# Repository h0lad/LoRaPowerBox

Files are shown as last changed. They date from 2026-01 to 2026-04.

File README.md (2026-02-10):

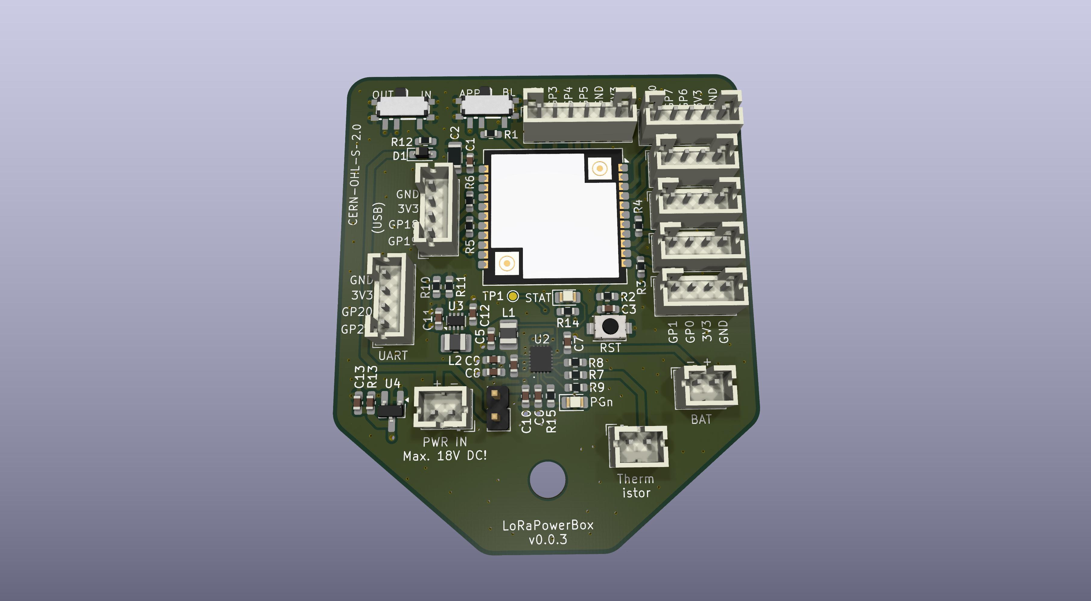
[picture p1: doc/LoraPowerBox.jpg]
LoRaPowerBox


## What is this thing?

This PCB integrates a Heltec HT-CT62 (ESP32-C3 + SX1262), a TI BQ25628E wide-range Li-ion charger and a TI TPS631000 buck-boost converter providing a stable 3.3V rail at up to 1.5A. The TI BQ25628E is capable of handling highly dynamic sources like solar cells and wind generators.

## Features

- 3.9-18V input range, with survival up to 26 V  
- Up to 3.2A input current (IBUS)  
- Up to 2A battery charge current (IBAT)  
- Up to 3.5A system output current (ISW), limited to 1.5A @ 3.3V by the TPS631000  
- Configurable hot/cold charging profile to restrict charging at extreme temperatures  
- Integrated ADC provides full voltage / current telemetry via I²C  
- Pseudo-MPPT (VINDPM + IINDPM) for improved energy harvesting from solar/wind/etc. sources
- Full protection circuitry, allowing operation even with unprotected LiPo cells  
- Reset IC (DI APX803L05) constantly monitors the battery voltage and switches off the 3.3V rail if it reaches a critical level - but keeps the charger always alive

You can see this project as a successor of the [SolarMeshtasticNode](https://github.com/h0lad/SolarMeshtasticNode) project which was a reliable work horse - but showed several limitations. 
Improvements:  

- No voltage dividers required - all measurements available via I²C from the charge controller
- No LED driver transistors needed
- Buck-architecture replaces inefficient LDO regulation
- Significantly improved access to interfaces

## Physical Outlines

The size of the PCB is 60mm x 51mm and is planned (= screw hole fits into housing) around following [Box (120x90x70)](https://de.aliexpress.com/item/1005005859929902.html). 

Do not use the transparent version: it will heat up.

**Simulation of the EdgeCut with a 1:1 print**

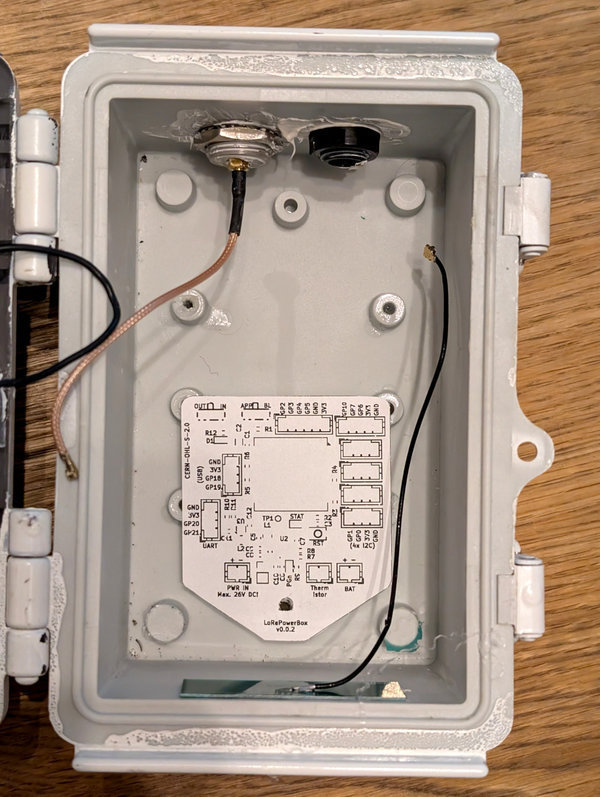
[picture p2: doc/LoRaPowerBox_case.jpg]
LoRaPowerBox


## Hardware Verification v0.2

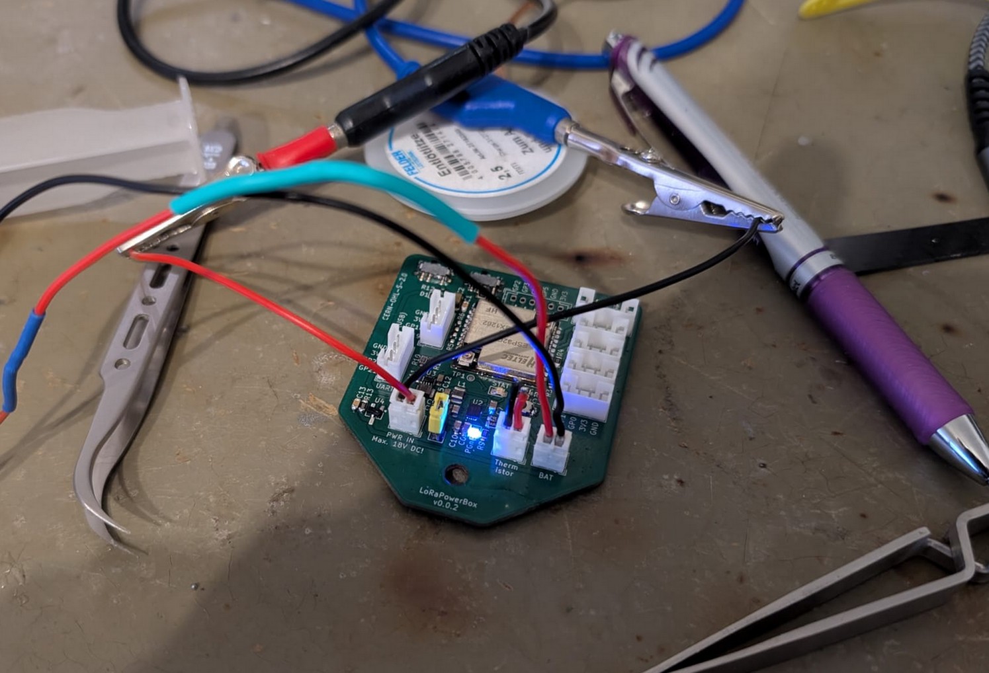
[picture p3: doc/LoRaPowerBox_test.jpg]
LoRaPowerBox


✅ Charging IC charges LiPo and blinks LED according to status

✅ Buck-Boost DCDC creates 3.3V

✅ Heating the thermistor forces throtteling of charging current

✅ Reset IC disables 3.3V using EN pin from DCDC if VBat falls below 3.2V

## FAQ

#### Why are you using a ESP32C3? 

I also do a lot of data gathering into TSDBs via Wifi. The Espressif has the most comfortable stack for doing this.

#### What pins does the LoRa module consume?

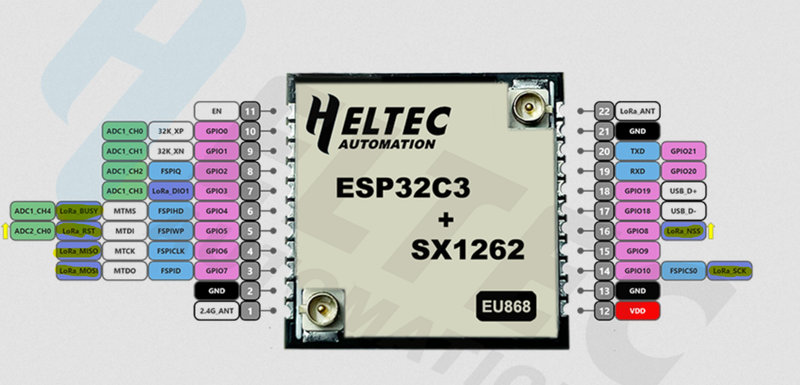
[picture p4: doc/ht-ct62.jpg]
Heltec HT-CT62


The Semtech SX1262 consumes a significant number of GPIOs.

Available pins If LoRa is being used: GPIO0, GPIO1, GPIO18, GPIO19, GPIO20, GPIO21

Note that GPIO8 and GPIO9 are strapping pins and are sampled during early boot.

If the SX1262 is not used, it can be disabled via its CS line (GPIO8) from application code.

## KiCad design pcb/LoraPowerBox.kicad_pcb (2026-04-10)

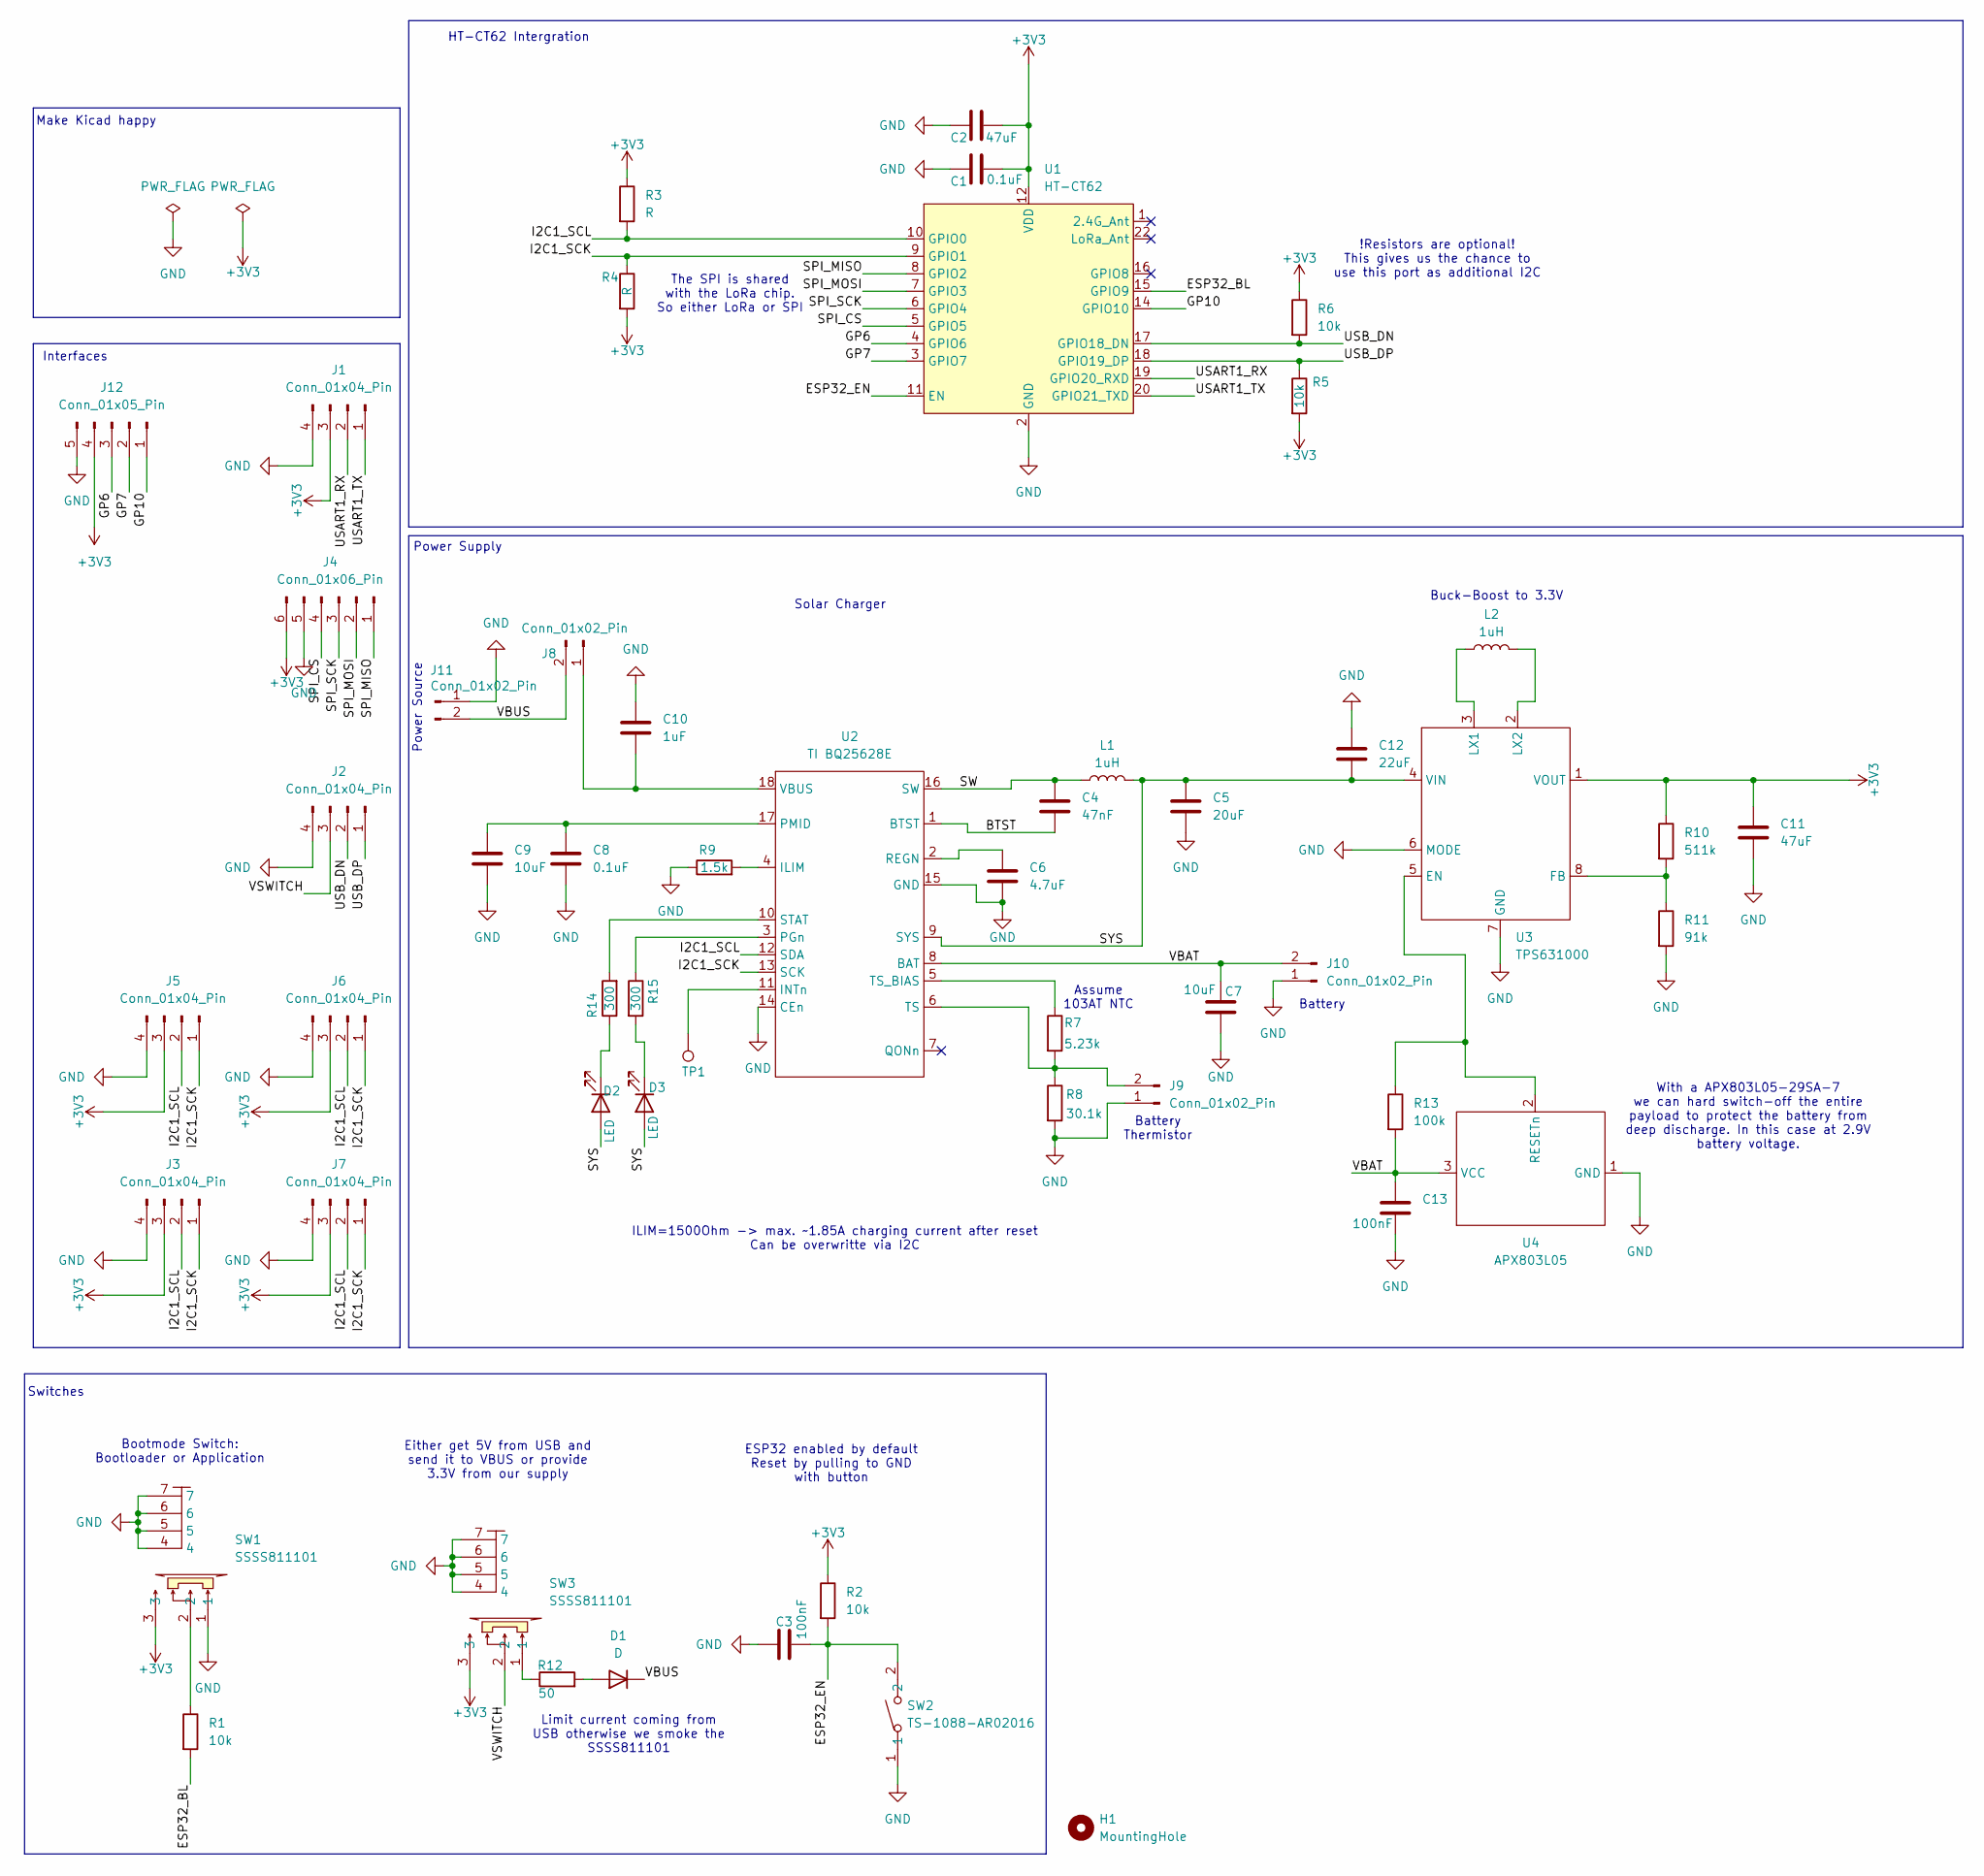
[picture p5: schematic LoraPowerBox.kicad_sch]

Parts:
C1, C8: 0.1uF; C_0603_1608Metric_Pad1.08x0.95mm_HandSolder
C2: 47uF; R_1206_3216Metric_Pad1.30x1.75mm_HandSolder
C3, C13: 100nF; C_0603_1608Metric_Pad1.08x0.95mm_HandSolder
C4: 47nF; C_0603_1608Metric_Pad1.08x0.95mm_HandSolder
C5: 20uF; C_0603_1608Metric_Pad1.08x0.95mm_HandSolder
C6: 4.7uF; C_0603_1608Metric_Pad1.08x0.95mm_HandSolder
C7, C9: 10uF; C_0603_1608Metric_Pad1.08x0.95mm_HandSolder
C10: 1uF; C_0603_1608Metric_Pad1.08x0.95mm_HandSolder
C11: 47uF; C_0603_1608Metric_Pad1.08x0.95mm_HandSolder
C12: 22uF; C_0603_1608Metric_Pad1.08x0.95mm_HandSolder
D1: D; D_SOD-323_HandSoldering
D2, D3: LED; LED_0805_2012Metric_Pad1.15x1.40mm_HandSolder
H1: MountingHole; MountingHole_4.3mm_M4_DIN965
J1, J2, J3, J5, J6, J7: Conn_01x04_Pin; JST_PH_B4B-PH-K_1x04_P2.00mm_Vertical
J4: Conn_01x06_Pin; JST_PH_B6B-PH-K_1x06_P2.00mm_Vertical
J8: Conn_01x02_Pin; PinHeader_1x02_P2.54mm_Vertical
J9, J10, J11: Conn_01x02_Pin; JST_PH_B2B-PH-K_1x02_P2.00mm_Vertical
J12: Conn_01x05_Pin; JST_PH_B5B-PH-K_1x05_P2.00mm_Vertical
L1, L2: 1uH; L_1008_2520Metric_Pad1.43x2.20mm_HandSolder
R1, R2, R5, R6: 10k; R_0603_1608Metric_Pad0.98x0.95mm_HandSolder
R3, R4: R; R_0603_1608Metric_Pad0.98x0.95mm_HandSolder
R7: 5.23k; R_0603_1608Metric_Pad0.98x0.95mm_HandSolder
R8: 30.1k; R_0603_1608Metric_Pad0.98x0.95mm_HandSolder
R9: 1.5k; R_0603_1608Metric_Pad0.98x0.95mm_HandSolder
R10: 511k; R_0603_1608Metric_Pad0.98x0.95mm_HandSolder
R11: 91k; R_0603_1608Metric_Pad0.98x0.95mm_HandSolder
R12: 50; R_0603_1608Metric_Pad0.98x0.95mm_HandSolder
R13: 100k; C_0603_1608Metric_Pad1.08x0.95mm_HandSolder
R14, R15: 300; R_0603_1608Metric_Pad0.98x0.95mm_HandSolder
SW1, SW3: SSSS811101; SW-SMD_SSSS811101; LCSC Part C109335
SW2: TS-1088-AR02016; SW-SMD_L3.9-W3.0-P4.45; LCSC Part C720477
TP1: TestPoint; TestPoint_Pad_D1.0mm
U1: HT-CT62; Heltec_HT-CT62
U2: TI BQ25628E; BQ25622ERYKR
U3: TPS631000; SOT-583-8
U4: APX803L05; SOT-23_Handsoldering

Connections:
+3V3: C1.2, C2.2, C11.1, J1.3, J3.3, J4.6, J5.3, J6.3, J7.3, J12.4, R2.1, R3.1, R4.2, R5.2, R6.1, R10.1, SW1.3, SW3.3, U1.12 (VDD), U3.1 (VOUT)
/BTST: C4.1, U2.1 (BTST)
/ESP32_BL: R1.2, U1.15 (GPIO9)
/ESP32_EN: C3.2, R2.2, SW2.2, U1.11 (EN)
/GP6: J12.3, U1.4 (GPIO6)
/GP7: J12.2, U1.3 (GPIO7)
/GP10: J12.1, U1.14 (GPIO10)
/I2C1_SCK: J3.1, J5.1, J6.1, J7.1, R4.1, U1.9 (GPIO1), U2.13 (SCK)
/I2C1_SCL: J3.2, J5.2, J6.2, J7.2, R3.2, U1.10 (GPIO0), U2.12 (SDA)
/SPI_CS: J4.4, U1.5 (GPIO5)
/SPI_MISO: J4.1, U1.8 (GPIO2)
/SPI_MOSI: J4.2, U1.7 (GPIO3)
/SPI_SCK: J4.3, U1.6 (GPIO4)
/SW: C4.2, L1.1, U2.16 (SW)
/SYS: C5.2, C12.2, D2.2 (A), D3.2 (A), L1.2, U2.9 (SYS), U3.4 (VIN)
/USART1_RX: J1.2, U1.19 (GPIO20_RXD)
/USART1_TX: J1.1, U1.20 (GPIO21_TXD)
/USB_DN: J2.2, R6.2, U1.17 (GPIO18_DN)
/USB_DP: J2.1, R5.1, U1.18 (GPIO19_DP)
/VBAT: C7.2, C13.2, J10.2, R13.2, U2.8 (BAT), U4.3 (VCC)
/VBUS: D1.1 (K), J8.2, J11.2
/VSWITCH: J2.3, SW3.2
GND: C1.1, C2.1, C3.1, C5.1, C6.1, C7.1, C8.1, C9.1, C10.2, C11.2, C12.1, C13.1, J1.4, J2.4, J3.4, J4.5, J5.4, J6.4, J7.4, J9.1, J10.1, J11.1, J12.5, R8.2, R9.1, R11.2, SW1.1, SW1.4, SW1.5, SW1.6, SW1.7, SW2.1, SW3.4, SW3.5, SW3.6, SW3.7, U1.2 (GND), U1.13 (GND), U1.21 (GND), U2.14 (CEn), U2.15 (GND), U3.6 (MODE), U3.7 (GND), U4.1 (GND)
unnamed: D1.2 (A), R12.2
unnamed: D2.1 (K), R14.1
unnamed: D3.1 (K), R15.2
unnamed: C10.1, J8.1, U2.18 (VBUS)
unnamed: J9.2, R7.2, R8.1, U2.6 (TS)
unnamed: R1.1, SW1.2
unnamed: R12.1, SW3.1
unnamed: R9.2, U2.4 (ILIM)
unnamed: TP1.1 (1_1), U2.11 (INTn)
unnamed: R15.1, U2.3 (PGn)
unnamed: C8.2, C9.2, U2.17 (PMID)
unnamed: C6.2, U2.2 (REGN)
unnamed: R14.2, U2.10 (STAT)
unnamed: R7.1, U2.5 (TS_BIAS)
unnamed: R13.1, U3.5 (EN), U4.2 (RESETn)
unnamed: R10.2, R11.1, U3.8 (FB)
unnamed: L2.1, U3.3 (LX1)
unnamed: L2.2, U3.2 (LX2)

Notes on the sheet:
ILIM=1500Ohm -> max. ~1.85A charging current after reset Can be overwritte via I2C
!Resistors are optional! This gives us the chance to use this port as additional I2C
The SPI is shared with the LoRa chip. So either LoRa or SPI
With a APX803L05-29SA-7 we can hard switch-off the entire payload to protect the battery from deep discharge. In this case at 2.9V battery voltage.
Power Source
HT-CT62 Intergration
Battery Thermistor
Power Supply
Bootmode Switch: Bootloader or Application
Buck-Boost to 3.3V
Limit current coming from USB otherwise we smoke the SSSS811101
Assume 103AT NTC
Battery
Interfaces
ESP32 enabled by default Reset by pulling to GND with button
Make Kicad happy
Either get 5V from USB and send it to VBUS or provide 3.3V from our supply
Switches
Solar Charger

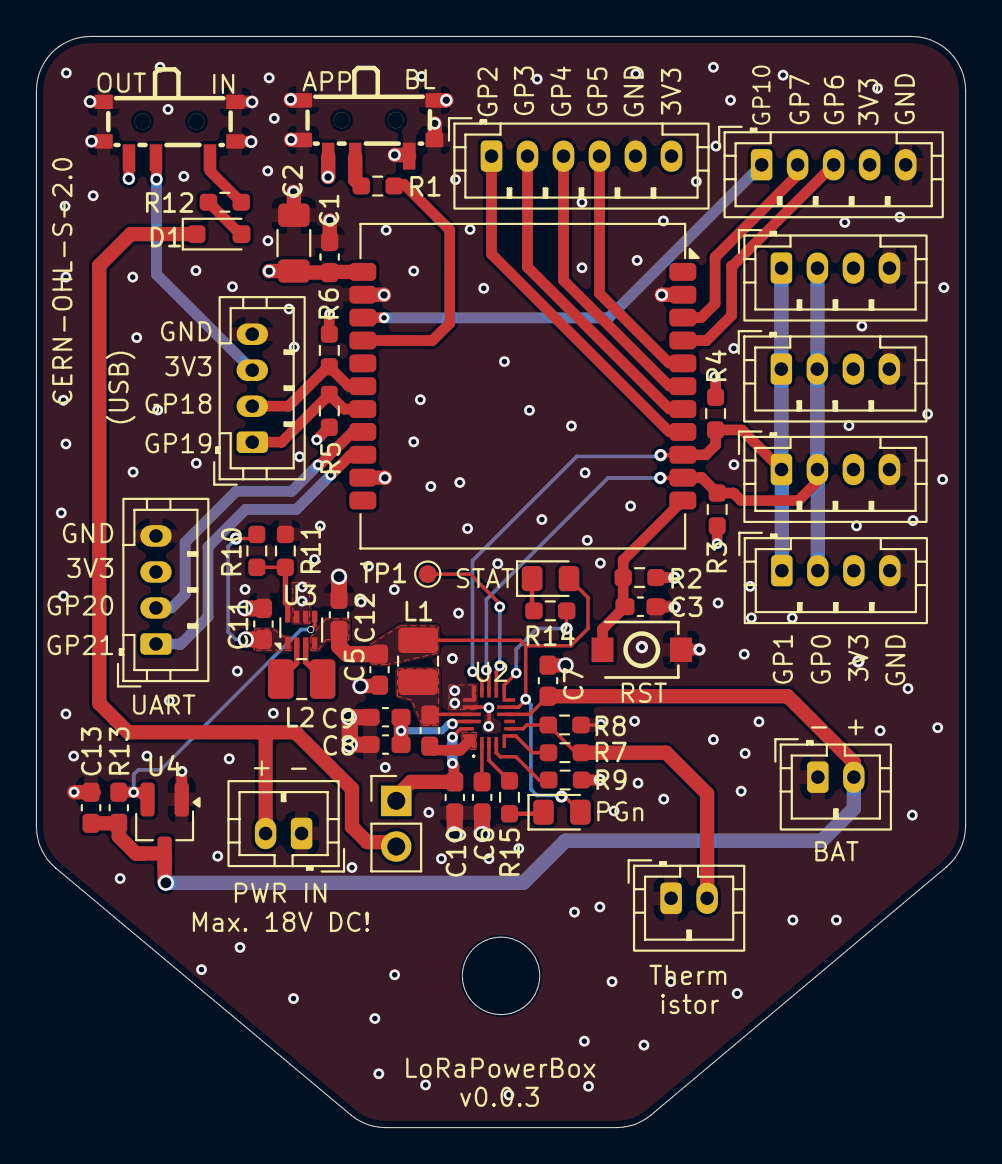
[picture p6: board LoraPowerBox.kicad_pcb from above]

Board: 4 copper layers, 51.6 x 60.6 mm, 54 parts (0 on the bottom side), 41 nets.

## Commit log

2025-12-29 pcb: reduce edge cut size a bit
    [LoraPowerBox.kicad_pcb]
2025-12-29 pcb: missed to fillet an edge
    [LoraPowerBox.kicad_pcb]
2025-12-29 pcb, sch: expose interrupt pin of charge controller to test pad
    [LoraPowerBox.kicad_sch]
2025-12-29 pcb: make it a little bit more symmetric
2025-12-29 pcb: non-functional clean ups
    [LoraPowerBox.kicad_pcb]
2025-12-29 pcb: fix another symmetry issue
    [LoraPowerBox.kicad_pcb]
2025-12-29 pcb: add a few more vias to gnd
    [LoraPowerBox.kicad_pcb]
2026-01-02 pcb, doc: move PWR IN a little bit to the left
    [LoraPowerBox.kicad_pcb]
2026-01-02 pcb, doc: opimize some silk prints
    [LoraPowerBox.kicad_pcb]
2026-01-02 pcb, sch: add resistor values for NTC voltage divider
    [LoraPowerBox.kicad_pcb, LoraPowerBox.kicad_sch]
2026-01-03 README: only Buck - no Boost
2026-01-03 README: be more precise about mounting hole
2026-01-04 pcb, sch: replace M3 hounting hole with M4
    [LoraPowerBox.kicad_pcb, LoraPowerBox.kicad_sch]
2026-01-04 pcb: the internal ADC maxes out at 18V. So rework silk print regaring voltage limits
    [LoraPowerBox.kicad_pcb]
2026-01-04 pcb: finally found the right kicad buttoms to center everything correctly
    [LoraPowerBox.kicad_pcb]
2026-01-05 sch, pcb: add reset IC that monitors the battery for us
    The BQ25628 has a UVLO (Battery Undervoltage Lockout) protection which
    is very very low (configurable voltages <2.5).
    Add an additional battery monitor which allows us to automatically
    switch off the 3.3V coming from the Buck-/Boost-Converter but keeps the
    BQ25628 alive so it can recharge the battery.
    [LoraPowerBox.kicad_pcb, LoraPowerBox.kicad_sch]
2026-01-05 pcb: eye candy - move reset ic a little bit to the left
    [LoraPowerBox.kicad_pcb]
2026-04-10 prj, pcb, sch: update to Kicad10
    [LoraPowerBox.kicad_pcb, LoraPowerBox.kicad_sch]
2026-04-10 pcb, sch: add a resistor to the LEDs
    [LoraPowerBox.kicad_pcb, LoraPowerBox.kicad_sch]

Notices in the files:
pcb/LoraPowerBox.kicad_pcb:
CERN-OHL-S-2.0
